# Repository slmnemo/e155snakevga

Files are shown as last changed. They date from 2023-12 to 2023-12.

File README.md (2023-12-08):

# Snake on VGA
HMC E155 MicroPs Final Project by Kaitlin Lucio and Diego Herrera Vicioso

## Directory Structure
```
├── docs
│   ├── _includes
│   └── assets
│       ├── img
│       └── schematics
├── fpga
│   ├── src
│   │   └── generic
│   └── testbench
│       └── testvectors
├── mcu
│   └── src
└── schematic
    └── lib
```
MCU Source code can be found in the mcu/src directory, and FPGA source code can be found in the fpga/src directory. FPGA testbenches can be found in the fpga/src/testbench directory. All sources for generating the project website are found in the docs directory. KiCAD schematic files are found in the schematic directory.

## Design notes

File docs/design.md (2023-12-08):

---
layout: page
title: Design
permalink: /design/
---
# Design Decisions
This project focused on using the VGA protocol at the industry standard 640x480 resolution at 60 Hz refresh rate. Holding RGB values for each pixel would require 3\*640\*480 = 921600 bits of memory, more than the FPGA can hold in flip flops or in RAM. Therefore, to mitigate this constraint, we partitioned the screen in 20 pixel square chunks, allowing us to use the onboard embedded block RAM on the FPGA. This results in a chunk resolution of 32 by 24. 

To minimize the data being sent from the MCU to the FPGA, the MCU only sends commands when pixels need to be updated. With this method, the screen does not have to be drawn from scratch every frame, saving precious computational power. This requires the FPGA to hold on to the values sent by the MCU. To accomplish this, the FPGA takes advantage of the onboard embedded block RAM. 

# MCU Design
The MCU in this design is responsible for handling user input, game logic, and display commands. User input is given through a set of four push buttons, which correspond to each direction the snake can move in. These buttons are tied to interrupts, allowing input to happen at any point during the calculations of game logic. This lets the inputs feel very responsive, as the input won't be missed due to polling at the wrong time. 

### SPI Communication Design
Communication between the FPGA and MCU is entirely controlled by the MCU, as the FPGA has no need to send data to the MCU. This communication is done over SPI with the following structure:
SPI Timing Diagram

The command, data1, and data2 bytes follow the following table:

| Command | Hex Encoding | Data Byte 1 | Data Byte 2 |
| --- | --- | --- | --- |
| Write Color Base Address | 0x80 | X Position | Y Position |
| Update Score | 0x10 | Score value MSBs | Score value LSBs |

To set a specific color with the Write Color Base Address command, the lowest 3 bytes of the command byte follow the following encoding:

| Lowest 3 bits of command | Color |
| --- | ----- |
| 0 | Black |
| 1 | Blue |
| 2 | Green |
| 3 | Cyan |
| 4 | Red |
| 5 | Purple |
| 6 | Yellow |
| 7 | White |

For example, to set the pixel chunk at (4,7) to red,
- command = 0x84
- data1 = 4
- data2 = 7

The update score command follows a similar structure, but no extra data is encoded in the command byte.

### Game Logic
The game logic implemented closely follows that of the classic snake game. That is to say, if the head of the tail runs into any part of the tail or the game borders, the game ends. Score is accumulated and snake tail is lengthened by eating the red "fruit". Go for as long as you can!

## MCU Block Diagram

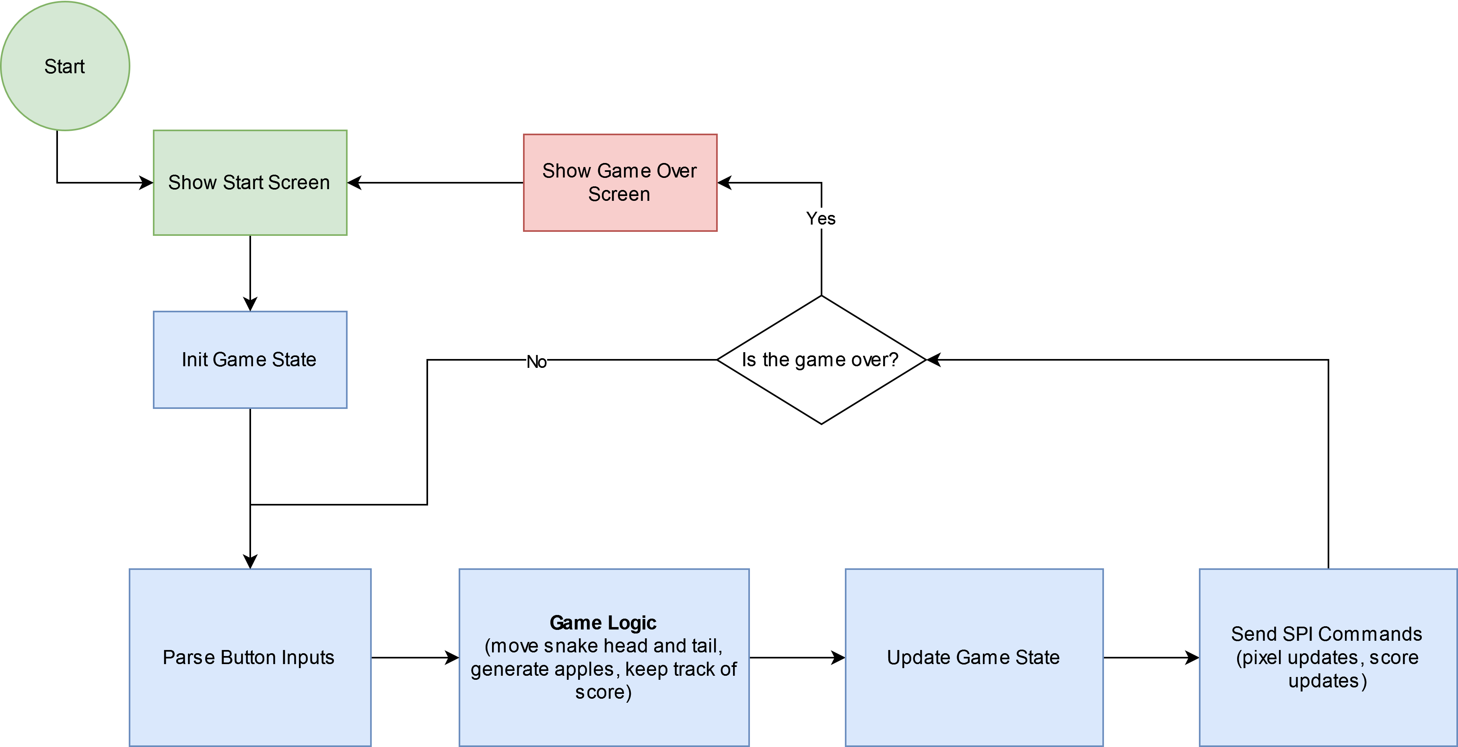
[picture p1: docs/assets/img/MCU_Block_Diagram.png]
MCU Block Diagram


# FPGA Design

The FPGA design consists of four main functional blocks:
- SPI Input and Decoder
- Memory 
- VGA Transmitter
- Score Decoder

All signals from the MCU to the FPGA are passed through synchronizers to avoid asynchronous behavior, especially when writing to the embedded block RAM which has a hold time constraint that needs to be obeyed. 

In addition, the VGA protocol for 640 x 480 @ 60 Hz is based off of a 25.175 MHz clock. To make timing match as closely as possible, the FPGA must use the same clock frequency to transmit pixels at the rate the monitor expects. To do this, the PLL module was instantiated using Radiant's IP generation functions. The frequency generated by the PLL was 25.125 MHz, which is within the tolerance on pixel clock frequency for this application of VGA. 

## SPI Input and Decoder

SPI inputs are decoded on the FPGA according to the specification listed in the [SPI Communication Design](#spi-communication-design) section. This consists of a controller that sends a trigger signal when the SPI chip select line drops from active to inactive. From here, SPI inputs are decoded and sent to their respective hardware. Pixel color write commands get sent to the RAM, while score update commands get sent to the score decoder hardware.

## Memory

Each 20 pixel wide chunk is stored in the RAM. For this use case, the RAM module used was 8 bits by 1024 entries. Since the address space for this is 10 bits, the x and y position of the pixel chunk can be encoded into an address with 5 bits each. In other words, the 5 most significant bits encode the y position of a chunk, and the 5 least significant bits encode the x position of a chunk. The lowest 3 bits in each memory location encoded the RGB values for that chunk.

To display the correct colors on the screen, the surrounding hardware has to fetch the color for the next chunk relative to the chunk the display is currently signaling.

### VGA Transmitter

These modules are responsible for pulsing the HSync and VSync lines, determining which RGB values to read in from memory, and transmitting all signals with the correct timing. This is accomplished with counters that keep track of which row and column is being sent out in a given frame. Importantly, it makes sure the porches (sections where no color data should be sent) are implemented properly in the VGA protocol.

### Score Decoder

These modules use the commands from SPI to display the score on the bottom right of the display. By using the current row and col values that the display is driving in a frame, it masks the RGB values to create a counter that resembles a seven segment display. In the spirit of MicroPs, the score is represented as a hexadecimal number. 

## FPGA Block Diagram

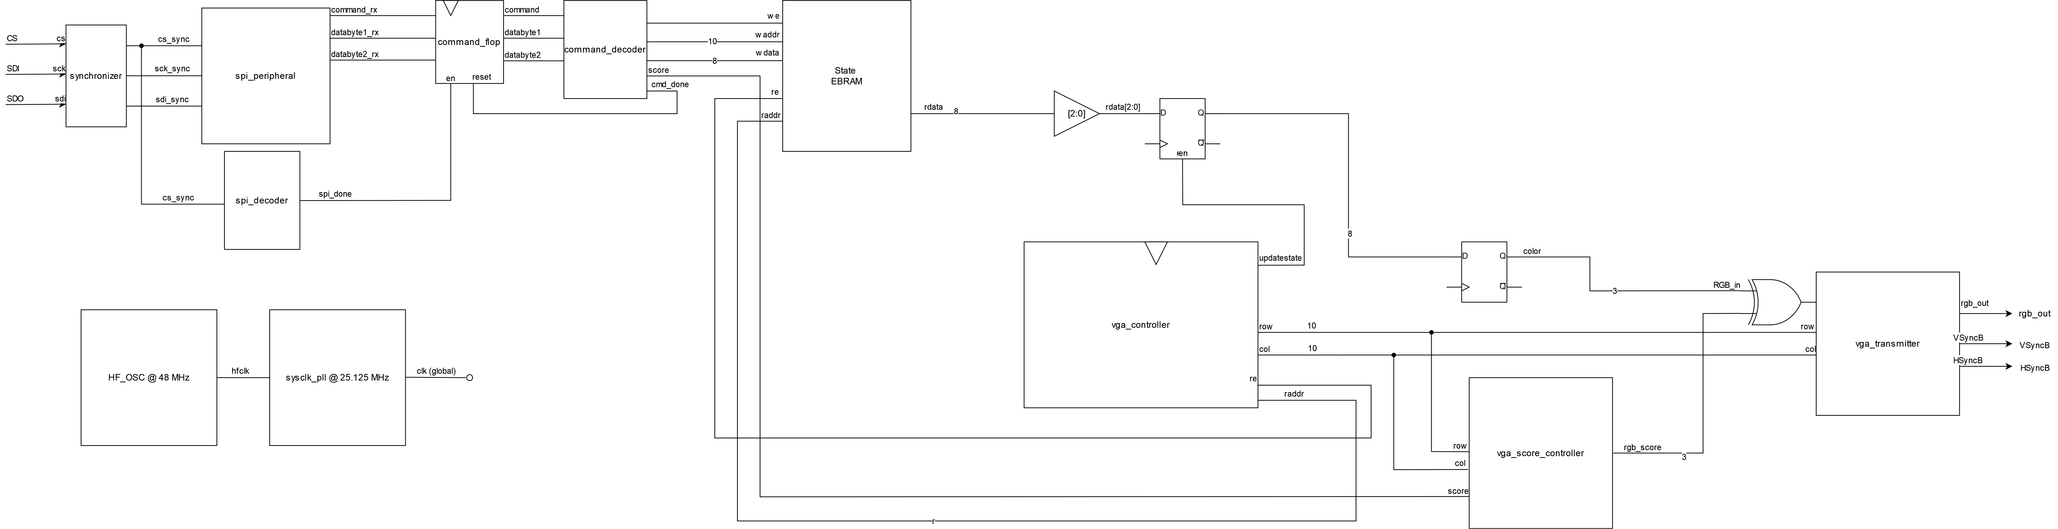
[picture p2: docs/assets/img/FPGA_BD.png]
FPGA Block Diagram


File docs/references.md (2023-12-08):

---
layout: page
title: References
permalink: /references/
---

# References
[1] TinyVGA 640 x 480 @ 60 Hz Industry Standard Timing http://www.tinyvga.com/vga-timing/640x480@60Hz

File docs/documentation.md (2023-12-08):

---
layout: page
title: Documentation
permalink: /doc/
---

# Schematics
<!-- Include images of the schematics for your system. They should follow best practices for schematic drawings with all parts and pins clearly labeled. You may draw your schematics either with a software tool or neatly by hand. -->

<embed src="{{ site.baseurl }}/assets/schematics/schematic.pdf" type="application/pdf" width="100%" height="500em"/>
<br>

# Source Code Overview
<!-- This section should include information to describe the organization of the code base and highlight how the code connects. -->

The source code for the project is located in the Github repository [here](https://github.com/slmnemo/e155snakevga).

# Bill of Materials
<!-- The bill of materials should include all the parts used in your project along with the prices and links.  -->

| Part | Manufacturer |	Quantity | Unit Price | Description |
| ---- | --- | ---| ----- | --- |
| Resistor 1.2k	| Stockroom	| 	3	| 	$0.00 |	Found in Stockroom |
| Resistor 1k	| Stockroom	| 	3	| 	$0.00 |	Found in Stockroom |
| Resistor 10k	| Stockroom	| 	3	| 	$0.00 |	Found in Stockroom |
| Resistor 270R	| Stockroom	| 	2	| 	$0.00 |	Found in Stockroom |
| DIP Button 	| Stockroom	| 	4	| 	$0.00 |	Found in Stockroom. Nice and clicky! |
| VGA Breakout Board	| Stockroom	| 	1	| 	$0.00 |	Found in Digital Lab |
| TN2106	| Stockroom	| 	2	| 	$0.00 |	N-type MOSFET, found in Digital Lab |
| 2N3904	| Stockroom	| 	3	| 	$0.00 |	NPN BJT, found in Digital Lab |

**Total cost: Free!** (provided the parts are laying around like they were here...)

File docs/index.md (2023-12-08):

---
layout: page
title: Project Overview
permalink: /
exclude: true
---

# Project Abstract
This is the project website for Kaitlin Lucio and Diego Herrera Vicioso's final project in E155 at HMC. 
Snake on VGA is a project designed to play around with video protocols while displaying a classic game.

# Project Motivation
This project was inspired by the look and feel of classic arcade-style games. We were interested in working on such a game,
but thought about what could make it interesting. So, the idea of displaying it on a regular, run-of-the-mill monitor (provided it has a VGA port, a less common protocol nowadays) was enticing. So we went for it!

# System Block Diagram

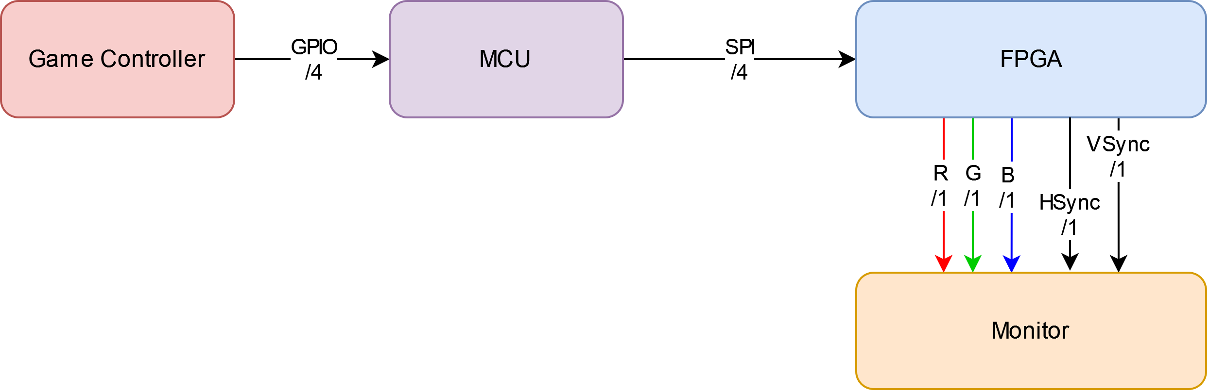
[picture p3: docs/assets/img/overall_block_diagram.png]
Overall Block Diagram


# Demo
{% include youtube.html id="BkBHMfGXC1A" %}

# Acknowledgements
We would like to thank Profs. Brake and Smilkstein for their support this semester in MicroPs. Couldn't have done it without you both!

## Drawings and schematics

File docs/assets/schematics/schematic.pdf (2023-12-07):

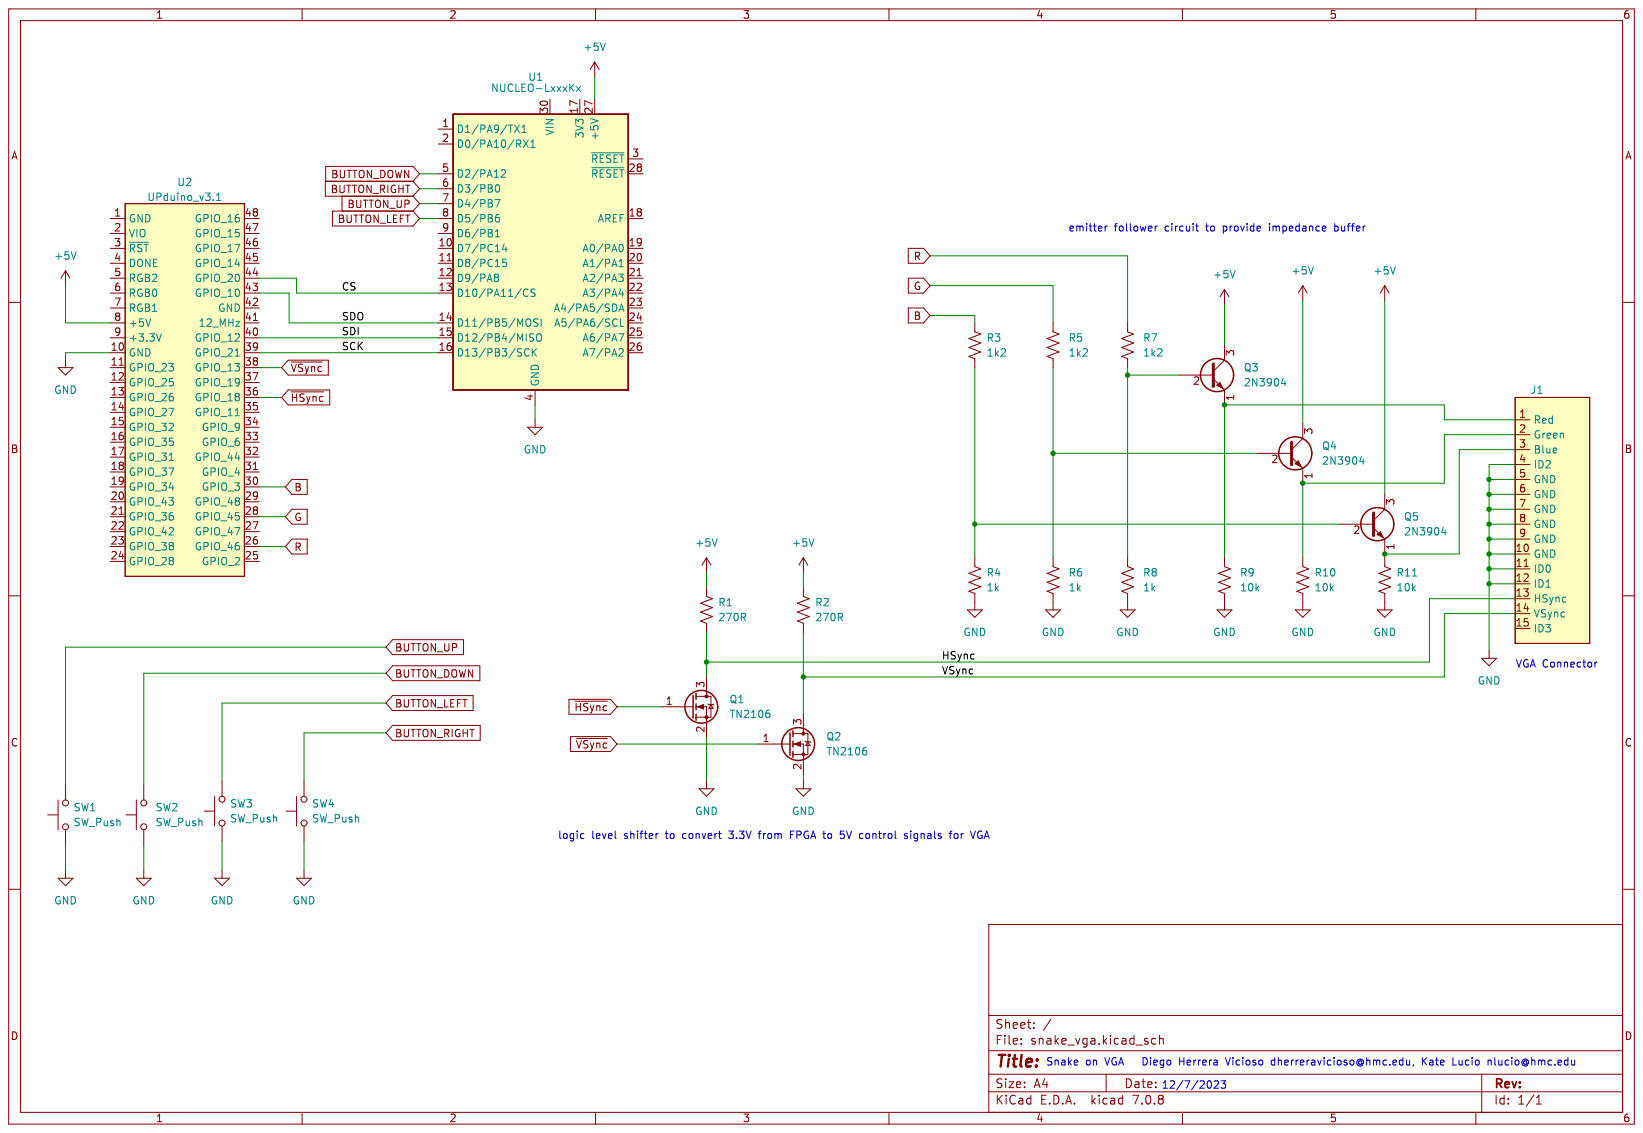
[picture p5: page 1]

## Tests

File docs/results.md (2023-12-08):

---
layout: page
title: Results
permalink: /results/
---

# Results
The specifications we set at the beginning of the project were:
1. FPGA is able to display frames on the monitor through a VGA connection
2. MCU is able to read input from the keypad and update the snake’s direction accordingly
3. MCU can send frames at a speed fast enough to update the monitor at 30 Hz.
4. Snake game logic matches the classic game

All specs were met at the end of the project, and some were even exceeded. The system is capable of displaying at 60 Hz rather than the 30 Hz in specification 3. Using one bit for each red, green, and blue field in each pixel yields 8 possible colors. A result from testing is shown below, where all 8 colors are displayed on the monitor in a fun pattern.
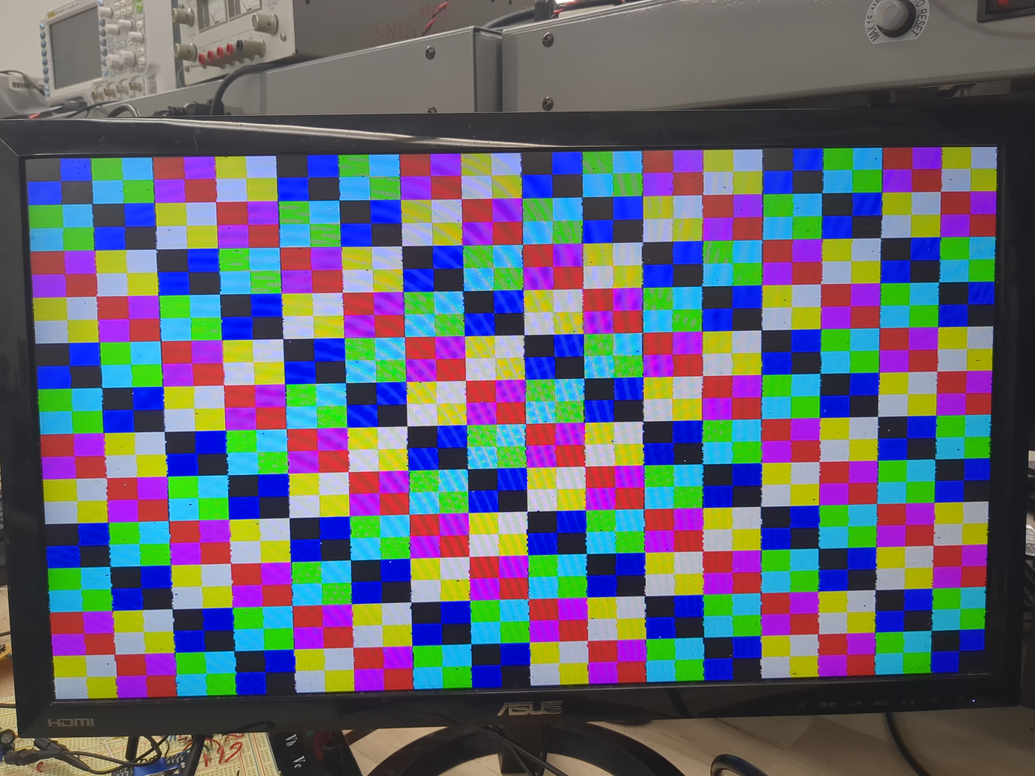
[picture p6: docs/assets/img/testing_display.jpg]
VGA Color Test


An interesting issue that we were unable to pin down was a "fuzziness" around the horizontal edges of chunks. We believe this to be some kind of off-by-one error in the VGA driver controller, but were unable to find the discrepancy based on timing the VGA signals outputted by the FPGA. There were no discrepancies between the timing standards defined in [1], but we still ran into this "fuzziness" problem. Nevertheless, the fuzziness does not affect the gameplay quality.

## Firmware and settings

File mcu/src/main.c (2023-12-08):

/*********************************************************************
*                    SEGGER Microcontroller GmbH                     *
*                        The Embedded Experts                        *
**********************************************************************

-------------------------- END-OF-HEADER -----------------------------

File    : main.c
Purpose : Generic application start

*/

#include <stdio.h>
#include <stdlib.h>
#include <stdint.h>
#include "main.h"

const int splash_screen[] =  {2, 3, 4, 5,  7, 11, 14, 15, 16, 17, 18, 21, 24, 26, 27, 28, 29, -1, // Line 0
                              2, 7, 8, 11, 14, 18, 21, 24, 26, -1, //line 1
                              2, 7, 8, 11, 14, 18, 21, 23, 24, 26, -1, // etc
                              3, 4, 5, 7, 9, 11, 14, 15, 16, 17, 18, 21, 22, 23, 26, 27, 28, -1,
                              5, 7, 10, 11, 14, 18, 21, 22, 23, 24, 26, -1,
                              5, 7, 10, 11, 14, 18, 21, 24, 26, -1,
                              2, 3, 4, 5, 7, 11, 14, 18, 21, 24, 26, 27, 28, 29, -1};


direction_t input_dir = STOP;
int score = 0;
int game_over = 0;

void init_interrupts() {
  // enable SYSCFG in RCC
  RCC->APB2ENR |= RCC_APB2ENR_SYSCFGEN;

  // Configure EXTICR
  SYSCFG->EXTICR[0] |= _VAL2FLD(SYSCFG_EXTICR1_EXTI0, 0b001); // PB0
  SYSCFG->EXTICR[1] |= _VAL2FLD(SYSCFG_EXTICR2_EXTI6, 0b001); // PB6
  SYSCFG->EXTICR[1] |= _VAL2FLD(SYSCFG_EXTICR2_EXTI7, 0b001); // PB7
  SYSCFG->EXTICR[3] |= _VAL2FLD(SYSCFG_EXTICR4_EXTI12, 0b000); // PA12

  // Enable interrupts globally
  __enable_irq();

  // Configure mask bits
  EXTI->IMR1 |= _VAL2FLD(EXTI_IMR1_IM0,  1);  // line 0
  EXTI->IMR1 |= _VAL2FLD(EXTI_IMR1_IM6,  1);  // line 6
  EXTI->IMR1 |= _VAL2FLD(EXTI_IMR1_IM7,  1);  // line 7
  EXTI->IMR1 |= _VAL2FLD(EXTI_IMR1_IM12, 1);  // line 12

  // Disable rising edge triggers
  EXTI->RTSR1 |= _VAL2FLD(EXTI_RTSR1_RT0,  0); // line 0
  EXTI->RTSR1 |= _VAL2FLD(EXTI_RTSR1_RT6,  0); // line 6
  EXTI->RTSR1 |= _VAL2FLD(EXTI_RTSR1_RT7,  0); // line 7
  EXTI->RTSR1 |= _VAL2FLD(EXTI_RTSR1_RT12, 0); // line 12

  // Enable falling edge trigger
  EXTI->FTSR1 |= _VAL2FLD(EXTI_FTSR1_FT0,  1); // line 0
  EXTI->FTSR1 |= _VAL2FLD(EXTI_FTSR1_FT6,  1); // line 6
  EXTI->FTSR1 |= _VAL2FLD(EXTI_FTSR1_FT7,  1); // line 7
  EXTI->FTSR1 |= _VAL2FLD(EXTI_FTSR1_FT12, 1); // line 12

  // Turn on EXTI interrupts in NVIC_ISER
  NVIC_EnableIRQ(EXTI0_IRQn);
  NVIC_EnableIRQ(EXTI9_5_IRQn);
  NVIC_EnableIRQ(EXTI15_10_IRQn);

  return;

}

void EXTI0_IRQHandler(void) {
    // Check that the button was what triggered our interrupt
    if (EXTI->PR1 & (1 << 0)) {
        // If so, clear the interrupt (NB: Write 1 to reset.)
        EXTI->PR1 |= (1 << 0);
        
        input_dir = RIGHT;

    }

    return;
}

void EXTI9_5_IRQHandler(void) {
    if (EXTI->PR1 & (1 << 6)) {
        // If so, clear the interrupt (NB: Write 1 to reset.)
        EXTI->PR1 |= (1 << 6);

        input_dir = LEFT;
        

    }

    if (EXTI->PR1 & (1 << 7)) {
        // If so, clear the interrupt (NB: Write 1 to reset.)
        EXTI->PR1 |= (1 << 7);

        input_dir = UP;

    }
    return;
}

void EXTI15_10_IRQHandler(void) {
    // Check that the button was what triggered our interrupt
    if (EXTI->PR1 & (1 << 12)) {
        // If so, clear the interrupt (NB: Write 1 to reset.)
        EXTI->PR1 |= (1 << 12);

        input_dir = DOWN;

    }

    return;
}

/*********************************************************************
*
*       main()
*
*  Function description
*   Application entry point.
*/
int main(void) {

  // Enable GPIOA clock
  RCC->AHB2ENR |= (RCC_AHB2ENR_GPIOAEN | RCC_AHB2ENR_GPIOBEN | RCC_AHB2ENR_GPIOCEN);

  // "clock divide" = master clock frequency / desired baud rate
  // the phase for the SPI clock is 0 and the polarity is 0
  initSPI(0, 0, 0);

  // initialize timer
  RCC->APB1ENR1 |= RCC_APB1ENR1_TIM2EN;
  RCC->APB1ENR1 |= RCC_APB1ENR1_TIM6EN;

  initTIM(DELAY_TIM_MS, 1e3); // give ms delay timing
  initTIM(DELAY_TIM_US, 1e6); // give us delay timing
  
  // button inputs
  pinMode(BUTTON_DOWN, GPIO_INPUT);
  pinMode(BUTTON_UP, GPIO_INPUT);
  pinMode(BUTTON_RIGHT, GPIO_INPUT);
  pinMode(BUTTON_LEFT, GPIO_INPUT);

  // enable pullups
  GPIOA->PUPDR |= _VAL2FLD(GPIO_PUPDR_PUPD12, 0b01); // Set PA12 as pull-up
  GPIOB->PUPDR |= _VAL2FLD(GPIO_PUPDR_PUPD7, 0b01); // Set PB7 as pull-up
  GPIOB->PUPDR |= _VAL2FLD(GPIO_PUPDR_PUPD6, 0b01); // Set PB6 as pull-up
  GPIOB->PUPDR |= _VAL2FLD(GPIO_PUPDR_PUPD0, 0b01); // Set PB0 as pull-up
  init_interrupts();

  while(1)
  {
    clear_screen();
    write_splash_screen(splash_screen);
    input_dir = STOP;
    while(input_dir == STOP); // wait for user input

    clear_screen();
    write_border(WHITE);
    init_game();

    while(!game_over) {
      input(input_dir);
      game_logic();
      delay_millis(DELAY_TIM_MS, 150);
    }
    // game is over
    input_dir = STOP;
    write_border(RED);
    while(input_dir == STOP); // wait for user input
    score = 0;
    
  }
}

/*************************** End of file ****************************/

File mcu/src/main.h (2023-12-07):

#ifndef MAIN_H
#define MAIN_H

#include "STM32L432KC.h"
#include "snake.h"

#define SPI_BEGIN digitalWrite(SPI_CS, 1); 
#define SPI_END digitalWrite(SPI_CS, 0);

#define BUTTON_DOWN PA12
#define BUTTON_UP PB7
#define BUTTON_LEFT PB6
#define BUTTON_RIGHT PB0

#define DELAY_TIM_MS TIM2
#define DELAY_TIM_US TIM6


#endif // MAIN_H

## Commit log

2023-11-14 Added SPI module + testbench
2023-11-15 Added MCU code with basic skeleton for game logic and SPI commands
2023-11-16 inverted HSync and VSync to make driver circuit easier
2023-11-16 Added board schematic + relevant ignores to .gitignore
    [snake_vga.kicad_pcb, snake_vga.kicad_sch]
2023-11-16 updated RGB resistor network
    [snake_vga.kicad_sch]
2023-11-16 updated grounds on VGA connector
    [snake_vga.kicad_sch]
2023-11-16 Moved to center of screen
    [snake_vga.kicad_sch]
2023-11-16 changed pullup resistor value for logic level shifter
    [snake_vga.kicad_sch]
2023-11-16 added sysclk_pll to source, fixed discrepancy between front and back porch of VSync and HSync
    [sysclk_pll.cfg]
2023-11-16 Fixed error where col is reset to 0 before next frame
2023-11-22 Exposed state to board LEDs
2023-11-27 parmetrized controller, fixed bugs in fsm, added 75 hz version
2023-11-30 Added module to generate write enable based on SPI signals
2023-12-01 Added and tested SPI modules
2023-12-01 (broken commit) parity across devices
    [command_decoder.sv]
2023-12-06 made changes related to fixing discrepancy in expectation between command decoder and spi output
    [command_decoder.sv]
2023-12-06 first pass at number offsets for score display, finalized pixel display driver
2023-12-07 Added timer for microsecond support
2023-12-07 Fixed write failure issues using synchronizers on spi signals and accounting for hold time on command reset.
    [command_decoder.sv]
2023-12-07 Finalized Schematic
    [snake_vga.kicad_sch]
2023-12-07 added schematic and block diagram
2023-12-07 rotated schematic, added BOM
2023-12-07 Removed unused SPI case
2023-12-07 removed kicad autogenerated file
2023-12-07 added spi docs
2023-12-08 fixed fruit generation logic
    [main.c, snake.c]
2023-12-08 added KiCAD explanation to README
2023-12-08 Revert "added KiCAD explanation to README" causing security issues?
    This reverts commit 0ab8a40f82ae6d72b44e0b1ef5aa2d3c234c2056.
